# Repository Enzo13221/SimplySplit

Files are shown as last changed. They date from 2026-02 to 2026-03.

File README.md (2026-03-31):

# SimplySplit
This is my low profile split keyboard. I made this because I really wanted to make a keyboard but also didnt want it to be too simple. This is why I made a bluetooth split keyboard. Because of it's small form factor it can "fit" into your pocket. This is useful as I really enjoy using my old RasPi on the go and a bt keyboard is realy useful.

## Images
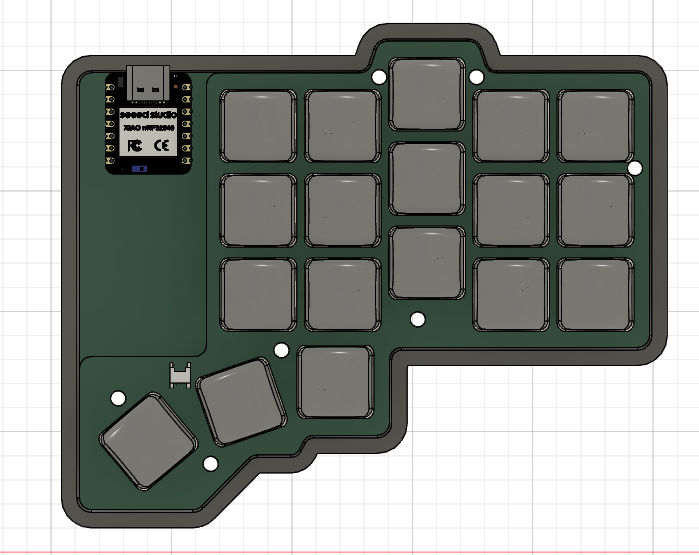
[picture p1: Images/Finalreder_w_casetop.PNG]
Final Render w Case Top


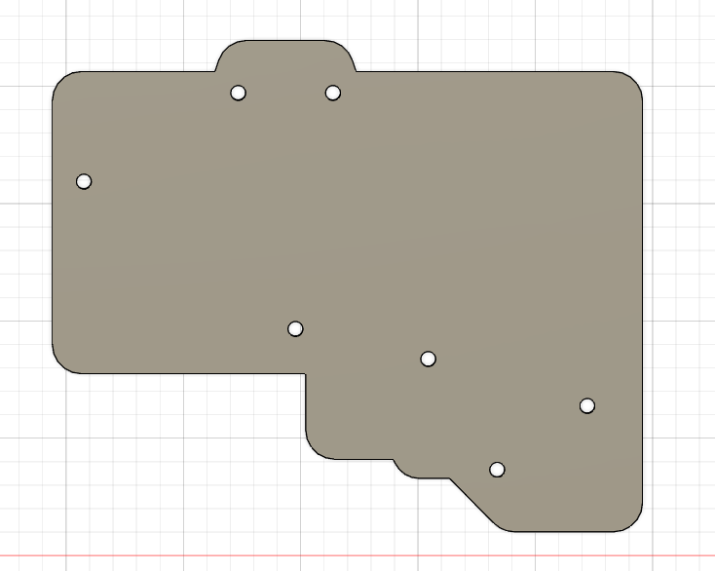
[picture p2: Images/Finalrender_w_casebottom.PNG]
Final Render w Case Bottom


(If you noticed that the connector for the Battery is being clipped by the top plate I decided to not use the connector but leave the footprint there as an option)

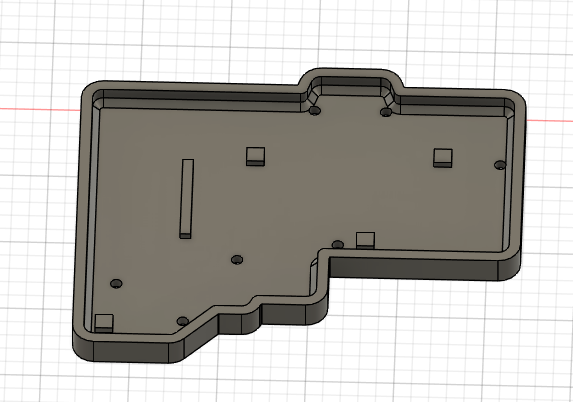
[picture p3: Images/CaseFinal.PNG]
Case Final






# Firmware can be found here

https://github.com/Enzo13221/ZMK-Config-SimplySplit 

# BOM
| Item | Description | Quantity | Unit price | Total price | Price + tax | Running total | Link |
| --- | --- | --- | --- | --- | --- | --- | --- |
| Keycaps | CFX, White | 40 | $0.33 | $13.07 | $14.77 | $14.77 | [AliExpress](https://www.aliexpress.us/item/3256810199199272.html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,scm-url:1007.40050.354490.0,pvid:384d1b43-ab82-45ca-9332-caee7cd0b6ae,tpp_buckets:668%232846%238107%231934&pdp_ext_f=%7B"order"%3A"22"%2C"eval"%3A"1"%2C"sceneId"%3A"30050"%2C"fromPage"%3A"recommend"%7D&pdp_npi=6%40dis%21USD%219.70%210.99%21%21%219.70%210.99%21%402101ea8c17712834864303402ea509%2112000052228852471%21rec%21US%21%21ABXZ%211%210%21n_tag%3A-29910%3Bd%3A5299cee1%3Bm03_new_user%3A-29895%3BpisId%3A5000000197847450&utparam-url=scene%3ApcDetailBottomMoreOtherSeller%7Cquery_from%3A%7Cx_object_id%3A1005010385514024%7C_p_origin_prod%3A) |
| Switches | Choc v1 brown | 40 | $0.74 | $14.87 | $16.80 | $31.57 | [AliExpress](https://www.aliexpress.us/item/3256806486085031.html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"order"%3A"97"%2C"eval"%3A"1"%2C"fromPage"%3A"search"%7D&pdp_npi=6%40dis%21USD%216.92%216.92%21%21%2147.48%2147.48%21%402103128817712830262832957ee54e%2112000037979106609%21sea%21US%210%21ABX%211%210%21n_tag%3A-29910%3Bd%3A5299cee1%3Bm03_new_user%3A-29895&curPageLogUid=fiXY8vuLofNm&utparam-url=scene%3Asearch%7Cquery_from%3A%7Cx_object_id%3A1005006672399783%7C_p_origin_prod%3A) |
| Batteries | 3.7V 200mAh | 2 | $2.84 | $5.68 | $6.42 | $37.99 | [AliExpress](https://www.aliexpress.us/item/2251832643018973.html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,scm-url:1007.40050.354490.0,pvid:02574686-c7bf-467c-94c4-5f7aa57118c0,tpp_buckets:668%232846%238111%231996&isseo=y&pdp_ext_f=%7B"order"%3A"116"%2C"eval"%3A"1"%2C"sceneId"%3A"30050"%2C"fromPage"%3A"recommend"%7D&pdp_npi=6%40dis%21USD%212.84%212.84%21%21%212.84%212.84%21%40210328df17712797568823146e484c%2112000040902843221%21rec%21US%21%21ABX%211%210%21n_tag%3A-29910%3Bd%3A5299cee1%3Bm03_new_user%3A-29895&utparam-url=scene%3ApcDetailTopMoreOtherSeller%7Cquery_from%3A%7Cx_object_id%3A32829333725%7C_p_origin_prod%3A)  |
| Molex Connector | WM1742-ND | 2 | $0.45 | $0.90 | $1.02 | $39.01 | [DigiKey](https://www.digikey.ca/en/products/detail/molex/0530480210/242864) |
| Resistor | MFR-25FBF52-806K | 2 | $0.14 | $0.28 | $0.32 | $39.32 | [DigiKey](https://www.digikey.ca/en/products/detail/yageo/MFR-25FBF52-806K/13696) |
| Resistor | HVR3700002004FR500 | 2 | $0.58 | $1.16 | $1.31 | $40.63 | [DigiKey](https://www.digikey.ca/en/products/detail/vishay-beyschlag-draloric-bc-components/HVR3700002004FR500/719532) |
| Diode | 1N4148W | 45 | $0.19 | $1.89 | $2.14 | $42.77 | [DigiKey](https://www.digikey.ca/en/products/detail/smc-diode-solutions/1N4148W/6022450) |
| PCB+Top plate | See attached image | 1 | $42.79 | $42.79 | $42.79 | $85.56 | N/A |
| Bolts | M3x20mm | 20 | $0.18 | $3.54 | $4.00 | $89.56 | [AliExpress](https://www.aliexpress.us/item/3256807895942562.html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"order"%3A"815"%2C"eval"%3A"1"%2C"fromPage"%3A"search"%7D&pdp_npi=6%40dis%21USD%211.64%210.99%21%21%211.64%210.99%21%402101e81117712966712334141eaf0b%2112000043609478511%21sea%21US%210%21ABX%211%210%21n_tag%3A-29910%3Bd%3A5299cee1%3Bm03_new_user%3A-29895%3BpisId%3A5000000198352206&curPageLogUid=pqj3T9RK0P7g&utparam-url=scene%3Asearch%7Cquery_from%3A%7Cx_object_id%3A1005008082257314%7C_p_origin_prod%3A) |
| Spacers | M3x6mmx1mm | 200 | $0.02 | $2.21 | $2.50 | $92.06 | [AliExpress](https://www.aliexpress.us/item/3256807407806741.html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"order"%3A"32"%2C"eval"%3A"1"%2C"fromPage"%3A"search"%7D&pdp_npi=6%40dis%21USD%212.21%210.99%21%21%2115.17%216.80%21%402103212b17712919601903092e4830%2112000041427681765%21sea%21US%210%21ABX%211%210%21n_tag%3A-29910%3Bd%3A5299cee1%3Bm03_new_user%3A-29895%3BpisId%3A5000000198352206&curPageLogUid=T75qFSRd0QTp&utparam-url=scene%3Asearch%7Cquery_from%3A%7Cx_object_id%3A1005007594121493%7C_p_origin_prod%3A) |

[BOM](https://docs.google.com/spreadsheets/d/1cfBUe_hsh4m0duevO8yELbZ5TltpPVcU9Z1VGttN0Io/edit?usp=sharing)

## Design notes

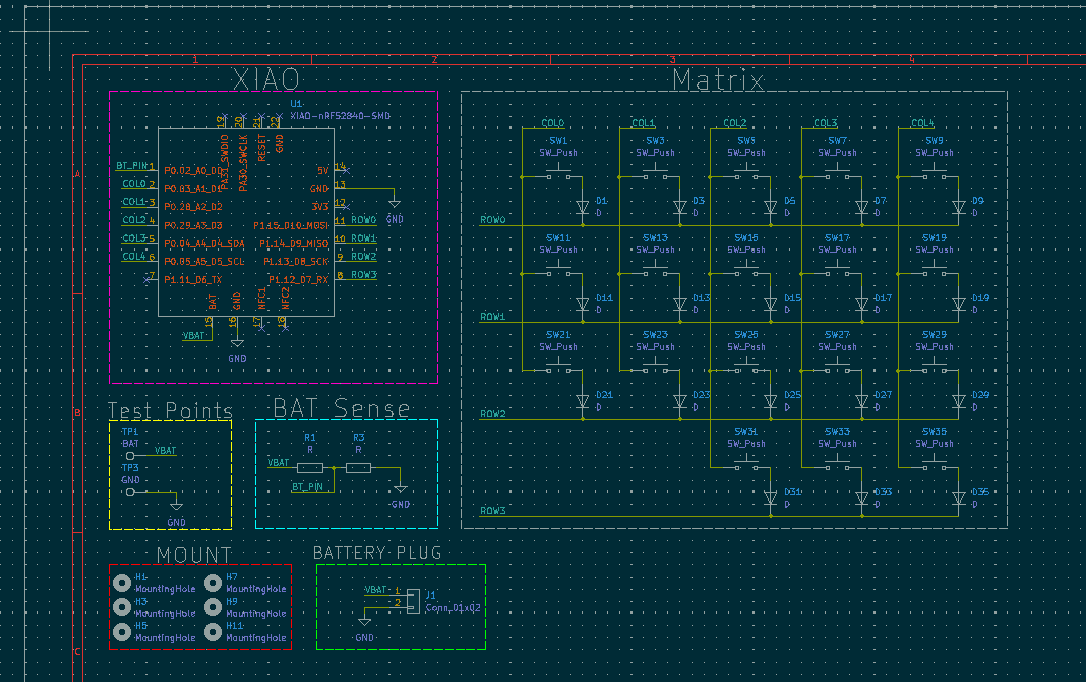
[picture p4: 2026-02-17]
Images/Schematic.PNG

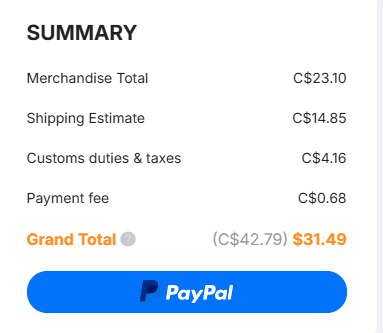
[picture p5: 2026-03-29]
Images/new price.PNG

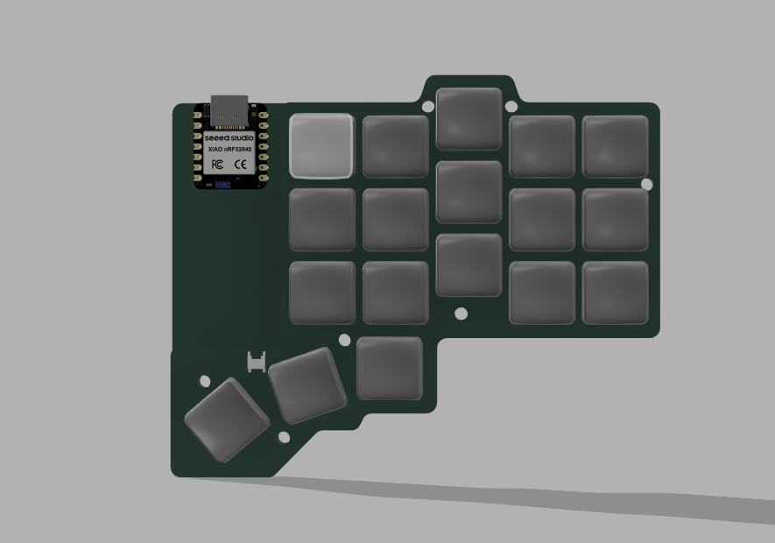
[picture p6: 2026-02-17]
Images/FinalRender.PNG

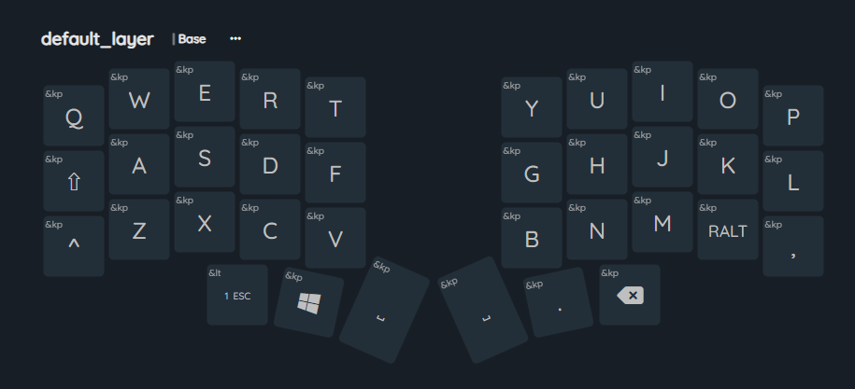
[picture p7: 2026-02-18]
Images/layout.PNG

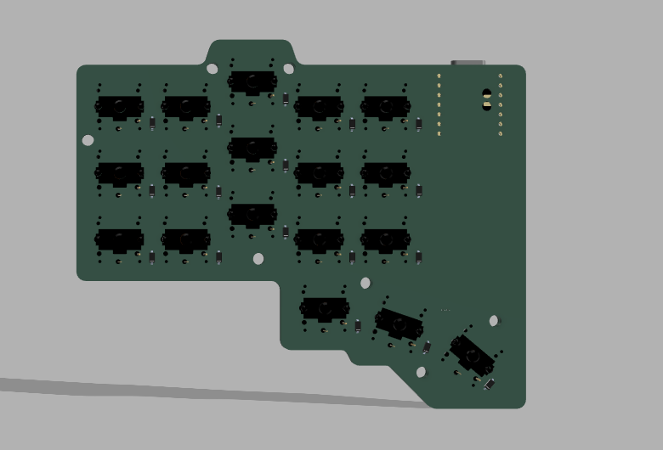
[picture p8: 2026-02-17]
Images/FinalRender(Back).PNG

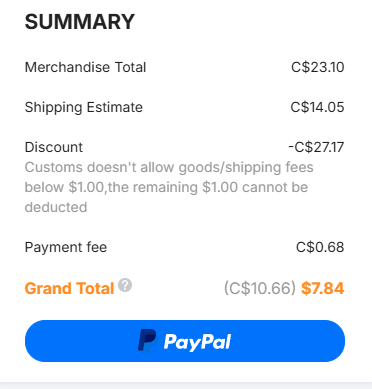
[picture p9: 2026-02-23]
Images/Updatedcost.PNG

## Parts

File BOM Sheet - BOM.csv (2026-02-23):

Item | Description | Quantity | Unit price | Total price | Price + tax | Running total | Link
Keycaps | CFX, White | 40 | $0.33 | $13.07 | $14.77 | $14.77 | https://www.aliexpress.us/item/3256810199199272.html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"order"%3A"22"%2C"eval"%3A"1"%2C"sceneId"%3A"30050"%2C"fromPage"%3A"recommend"%7D&pdp_npi=6%40dis%21USD%219.70%210.99%21%21%219.70%210.99%21%402101ea8c17712834864303402ea509%2112000052228852471%21rec%21US%21%21ABXZ%211%210%21n_tag%3A-29910%3Bd%3A5299cee1%3Bm03_new_user%3A-29895%3BpisId%3A5000000197847450&utparam-url=scene%3ApcDetailBottomMoreOtherSeller%7Cquery_from%3A%7Cx_object_id%3A1005010385514024%7C_p_origin_prod%3A
Switches | Choc v1 brown | 40 | $0.74 | $14.87 | $16.80 | $31.57 | https://www.aliexpress.us/item/3256808564997279.html?mp=1
Batteries | 3.7V 200mAh | 2 | $2.84 | $5.68 | $6.42 | $37.99 | https://www.aliexpress.us/item/2251832643018973.html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"order"%3A"116"%2C"eval"%3A"1"%2C"sceneId"%3A"30050"%2C"fromPage"%3A"recommend"%7D&pdp_npi=6%40dis%21USD%212.84%212.84%21%21%212.84%212.84%21%40210328df17712797568823146e484c%2112000040902843221%21rec%21US%21%21ABX%211%210%21n_tag%3A-29910%3Bd%3A5299cee1%3Bm03_new_user%3A-29895&utparam-url=scene%3ApcDetailTopMoreOtherSeller%7Cquery_from%3A%7Cx_object_id%3A32829333725%7C_p_origin_prod%3A
Molex Connector | WM1742-ND | 2 | $0.45 | $0.90 | $1.02 | $39.01 | https://www.digikey.ca/en/products/detail/molex/0530480210/242864
Resistor | MFR-25FBF52-806K | 2 | $0.14 | $0.28 | $0.32 | $39.32 | https://www.digikey.ca/en/products/detail/yageo/MFR-25FBF52-806K/13696
Resistor | HVR3700002004FR500 | 2 | $0.58 | $1.16 | $1.31 | $40.63 | https://www.digikey.ca/en/products/detail/vishay-beyschlag-draloric-bc-components/HVR3700002004FR500/719532
Diode | 1N4148W | 100 | $0.19 | $1.89 | $2.14 | $42.77 | https://www.aliexpress.us/item/3256806974248533.html?mp=1
PCB+Top plate | Picture will be attatched as I cant link to JLC | 1 | $5.33 | $6.82 | $7.71 | $50.48 | IMG to be attached in images on repo
Bolts | M3x20mm | 20 | $0.18 | $3.54 | $4.00 | $54.48 | https://www.aliexpress.us/item/3256807895942562.html?pdp_ext_f=%7B"order"%3A"815"%2C"eval"%3A"1"%2C"fromPage"%3A"search"%7D&pdp_npi=6%40dis%21USD%211.64%210.99%21%21%211.64%210.99%21%402101e81117712966712334141eaf0b%2112000043609478511%21sea%21US%210%21ABX%211%210%21n_tag%3A-29910%3Bd%3A5299cee1%3Bm03_new_user%3A-29895%3BpisId%3A5000000198352206&curPageLogUid=pqj3T9RK0P7g&utparam-url=scene%3Asearch%7Cquery_from%3A%7Cx_object_id%3A1005008082257314%7C_p_origin_prod%3A
Spacers | M3x6mmx1mm | 200 | $0.02 | $2.21 | $2.50 | $56.97 | https://www.aliexpress.us/item/3256807407806741.html?pdp_ext_f=%7B"order"%3A"32"%2C"eval"%3A"1"%2C"fromPage"%3A"search"%7D&pdp_npi=6%40dis%21USD%212.21%210.99%21%21%2115.17%216.80%21%402103212b17712919601903092e4830%2112000041427681765%21sea%21US%210%21ABX%211%210%21n_tag%3A-29910%3Bd%3A5299cee1%3Bm03_new_user%3A-29895%3BpisId%3A5000000198352206&curPageLogUid=T75qFSRd0QTp&utparam-url=scene%3Asearch%7Cquery_from%3A%7Cx_object_id%3A1005007594121493%7C_p_origin_prod%3A

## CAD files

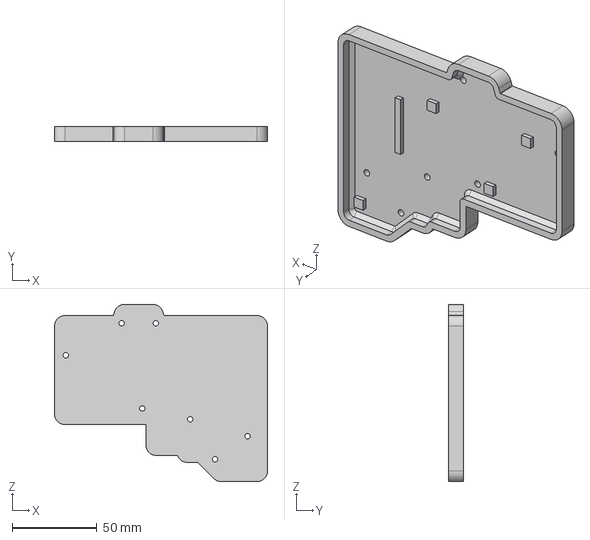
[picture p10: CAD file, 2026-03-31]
Fabrication/Simply Splitfinal CASE UPD.step
125.8 x 8.64 x 104.7 mm

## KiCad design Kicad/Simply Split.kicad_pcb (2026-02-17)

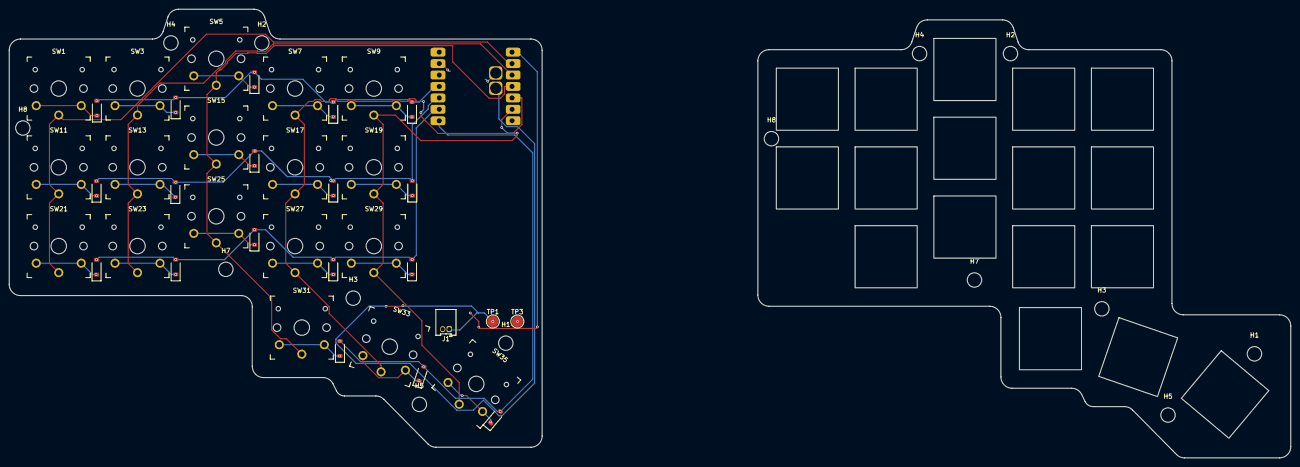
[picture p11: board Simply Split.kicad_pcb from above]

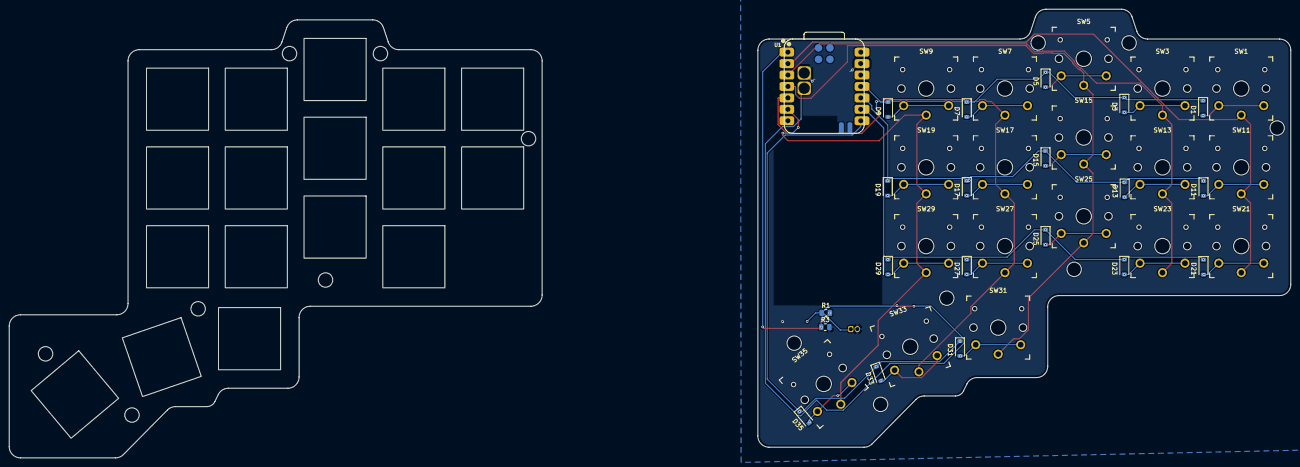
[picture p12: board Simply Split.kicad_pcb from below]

Board: 2 copper layers, 118.4 x 97.3 mm, 56 parts (21 on the bottom side), 30 nets.

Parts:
D1, D3, D5, D7, D9, D11, D13, D15, D17, D19, D21, D23, D25, D27, D29, D31, D33, D35: D; diode123reverse
H1, H1#2, H2, H2#2, H3, H3#2, H4, H4#2, H5, H5#2, H7, H7#2, H8, H8#2: MountingHole; MountingHole_3.2mm_M3
J1: Conn_01x02; Molex_PicoBlade_53048-0210_1x02_P1.25mm_Horizontal
R1, R3: R; R_0805_2012Metric
SW1, SW3, SW5, SW7, SW9, SW11, SW13, SW15, SW17, SW19, SW21, SW23, SW25, SW27, SW29, SW31, SW33, SW35: SW_Push; SW_PG1350_reversible
TP1: BAT; TestPoint_Pad_D2.5mm
TP3: GND; TestPoint_Pad_D2.5mm
U1: XIAO-nRF52840-SMD; modified-XIAO-nRF52840-SMD (1)

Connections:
/Left/BT_PIN: R1.2, R3.1, U1.1 (P0.02_A0_D0)
/Left/COL0: SW1.1, SW11.1, SW21.1, U1.2 (P0.03_A1_D1)
/Left/COL1: SW3.1, SW13.1, SW23.1, U1.3 (P0.28_A2_D2)
/Left/COL2: SW5.1, SW15.1, SW25.1, SW31.1, U1.4 (P0.29_A3_D3)
/Left/COL3: SW7.1, SW17.1, SW27.1, SW33.1, U1.5 (P0.04_A4_D4_SDA)
/Left/COL4: SW9.1, SW19.1, SW29.1, SW35.1, U1.6 (P0.05_A5_D5_SCL)
/Left/ROW0: D1.1 (K), D3.1 (K), D5.1 (K), D7.1 (K), D9.1 (K), U1.11 (P1.15_D10_MOSI)
/Left/ROW1: D11.1 (K), D13.1 (K), D15.1 (K), D17.1 (K), D19.1 (K), U1.10 (P1.14_D9_MISO)
/Left/ROW2: D21.1 (K), D23.1 (K), D25.1 (K), D27.1 (K), D29.1 (K), U1.9 (P1.13_D8_SCK)
/Left/ROW3: D31.1 (K), D33.1 (K), D35.1 (K), U1.8 (P1.12_D7_RX)
/Left/VBAT: J1.1, R1.1, TP1.1, U1.15 (BAT)
GND: J1.2, R3.2, TP3.1, U1.13 (GND), U1.16 (GND)
unnamed: D1.2 (A), SW1.2
unnamed: D3.2 (A), SW3.2
unnamed: D5.2 (A), SW5.2
unnamed: D7.2 (A), SW7.2
unnamed: D9.2 (A), SW9.2
unnamed: D11.2 (A), SW11.2
unnamed: D13.2 (A), SW13.2
unnamed: D15.2 (A), SW15.2
unnamed: D17.2 (A), SW17.2
unnamed: D19.2 (A), SW19.2
unnamed: D21.2 (A), SW21.2
unnamed: D23.2 (A), SW23.2
unnamed: D25.2 (A), SW25.2
unnamed: D27.2 (A), SW27.2
unnamed: D29.2 (A), SW29.2
unnamed: D31.2 (A), SW31.2
unnamed: D33.2 (A), SW33.2
unnamed: D35.2 (A), SW35.2

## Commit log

2026-02-17 Added BOM
2026-02-17 Fix BOM
2026-02-17 First big commit
    [Simply Split.kicad_pcb, side.kicad_sch]
2026-02-17 added spacers
    [BOM Sheet - BOM.csv]
2026-02-17 Moved BOM to root
    [BOM Sheet - BOM.csv]
2026-02-17 Fixed repo as requested
    [Simply Split.kicad_pcb, Simply Split.kicad_sch, side.kicad_sch]
2026-02-23 Updates to prices
    [BOM Sheet - BOM.csv]
2026-03-29 Case created
    [Simply Splitfinal CASE.step]
2026-03-31 Fixed case file
    [Simply Splitfinal CASE UPD.step, Simply Splitfinal CASE.step]
2026-03-31 Fixed assembled
